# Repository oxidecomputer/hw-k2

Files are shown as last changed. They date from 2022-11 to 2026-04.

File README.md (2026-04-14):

# hw-k2



This design provides a PCIe extender that converts from
a U.2 PCIe device connector and provides a x4 PCIe CEM slot.

This is designed to work on *our* gimlet computer sled with a 
sharkfin PCIe riser.  Whether this can be generally used in
other applications is unknown.

This repository includes a 3d-printable encolosure design that
fits in our sled and provides brackets for both of the commonly
used NICs.

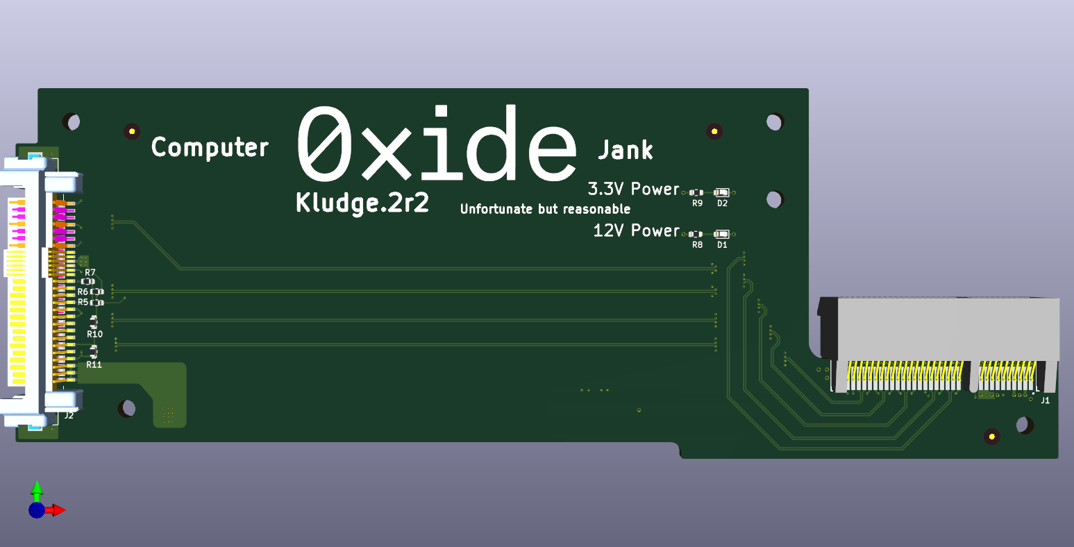
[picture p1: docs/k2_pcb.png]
PCB render


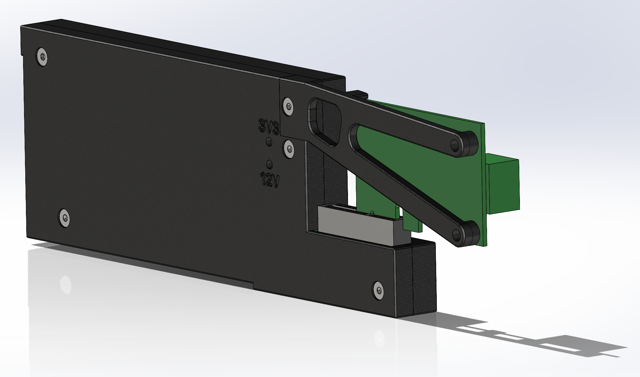
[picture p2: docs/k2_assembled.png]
exploded


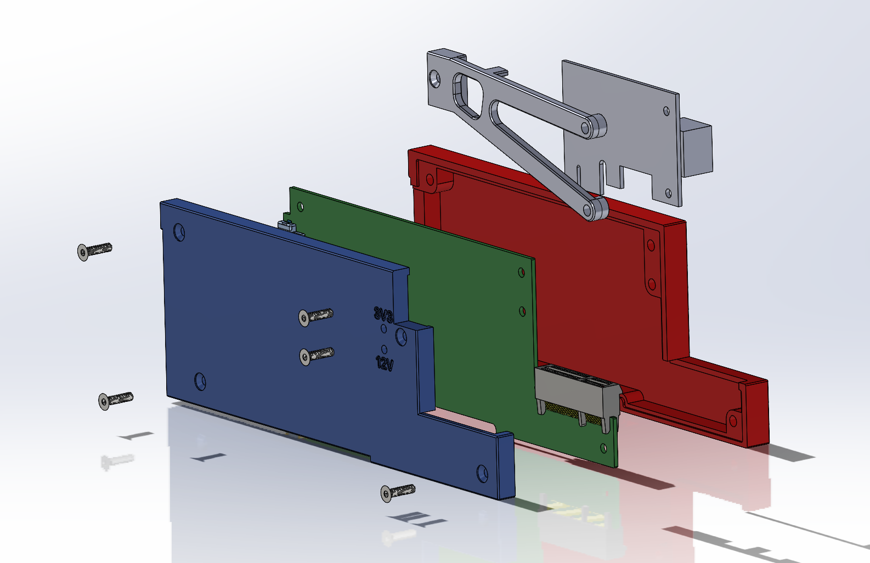
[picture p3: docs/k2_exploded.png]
assembled


[Mechanicals](mech_model)

# Status
The CAD represents a functional design.

# PLM

For the sake of clarity and consistency, the PLM-released files are renamed and
organized in the `plm` directory.

| PLM Name | Repo Name |
| --- | --- |
| 913-0000114_rev1_v1.d356 | gerbers/u2CEM.d356
| 913-0000114_rev1_v1_bom.xlsx | pulled out of the gerber zip
| 913-0000114_rev1_v1_gerbers.zip | gerbers/913-0000114_rev1.zip
| 913-0000114_rev1_v1_odb.zip | gerbers/u2CEM-odb.zip
| 913-0000114_rev1_v1_schematic.pdf | 913-0000114.pdf
| 913-0000114_rev1_v1_stackup.xlsx | stackup-K2-6lyr-FR408HR_rev4_26_MAR_2026.xlsx

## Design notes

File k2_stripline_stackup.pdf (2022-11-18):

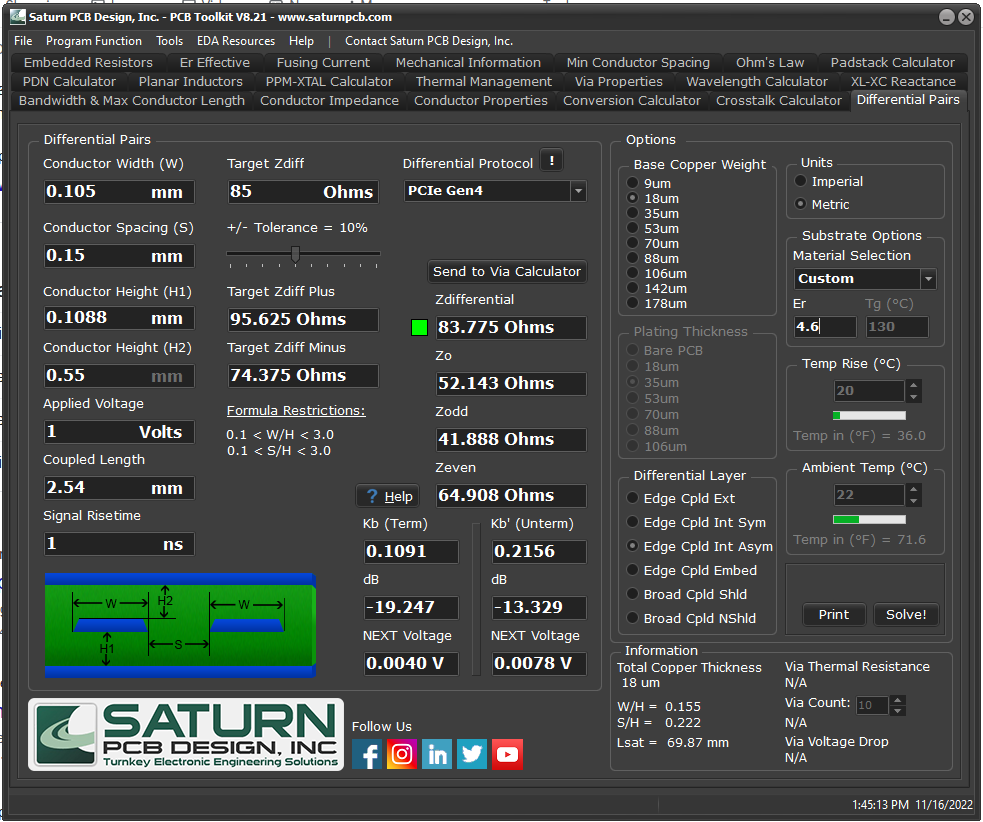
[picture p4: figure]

FR4 prepreg

Copper

FR4 prepreg

FR4 Core

Copper

IN2

IN3

IN4

FR4 Core
H = 0.55 mm
er = 4.6
tand = 0.02

FR4 Prepreg
H = 0.1088 mm
er = 4.25
tand = 0.02

Dielectric3

Dielectric4

Diagram is approximately to scale!
IN2, IN3, and IN4 copper thickness = 0.0152 mm (about 0.5 oz?)

Assume that the prepreg laminates itself in around the IN3 core traces

For 100 Ohm differential stripline: Trace width = 0.105 mm
Differential pair trace gap = 0.15 mm Zdiff (assume er=4.6) = 83.775 Ohms Zdiff (assume er = 4.25) = 87.157 Ohms

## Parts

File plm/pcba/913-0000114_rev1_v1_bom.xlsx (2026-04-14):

BOM: 913-0000103
Assembly Part Number/Revision: 913-0000103_rev1
Oxide Computer Company
Item # | Quantity per board | Manufacturer Part # | Do Not Install | Reference designators | Vendor (optional) | Vendor Part Number (optional) | Value (optional) | Size / Footprint (optional) | Part description/ specs (optional, but recommended) | Manfacturer (optional)
1 | 1 | GRM155R61E105KA12D |  | C1 | DigiKey | 490-10017-1-ND | 1uF |  | CAP CER 1UF 25V X5R 0402 | Murata Electronics
2 | 1 | RMCF0402FT10K0 | DNI | R1 | Digikey | RMCF0402FT10K0CT-ND | 10k |  | RES 10K OHM 1% 1/16W 0402 | Stackpole
3 | 4 | 5015 | DNI | TP1,TP2,TP3,TP4 | Digikey | 36-5015CT-ND |  |  | PC TEST POINT MINIATURE | Keystone
4 | 1 | SN74LVC1G07DBVR |  | U1 | Digikey | 296-8485-1-ND |  |  | IC BUFF NON-INVERT 5.5V SOT-23-5 | Texas Instruments
END OF BOM

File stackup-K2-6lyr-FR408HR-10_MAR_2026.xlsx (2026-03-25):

Design_Stackup
Customer |  | Oxide Computer Company
Board Title |  | K.2
Part Number |  | 913-0000114
Layer Count |  | 6L
Thickness (mils) |  | 62mil +/- 10%
Material |  | FR408HR
Copper Foil |  | Standard
Soldermask |  | Black
Other demands |  | N/A
Date |  | 2026-03-10
Revision |  | V01
Layer | Type | Material | Glass gabric (RC%) | Copper foil |  | Thickness |  | Dk @10GHz | Df @10GHz | Ref Plane | Differential ( trace / space )
 |  |  |  |  |  |  |  |  |  |  | 85 Ohm +/- 10%
 |  |  |  |  |  |  |  |  |  |  | Design LW | Actual LW
 |  |  |  | weight (oz) | type, Rz(um) | mils | Tolerance |  |  |  | mils | mils
 | SOLDERMASK | SOLDERMASK |  |  |  | 0.500 |  | 3.50 | 0.0190
L1 | CONDUCTOR |  |  | 1/4 OZ COPPER + PLATE |  | 1.450 |  |  |  | L2 | 5.5 / 11.5
 | Prepreg | FR408HR | 1086x1 RC65% |  |  | 2.996 |  | 3.26 | 0.0028
L2 | CONDUCTOR |  |  | 1 OZ COPPER |  | 1.400
 | Core | FR408HR | 2116x1 RC54% |  |  | 5.000 |  | 3.23 | 0.0042
L3 | CONDUCTOR |  |  | 1 OZ COPPER |  | 1.400 |  |  |  | L2 & L6 | 6.8 / 12.8
 | Prepreg | FR408HR | 106x1 RC75% 1080x1 RC71% 106x1 RC75% |  |  | 7.536
 | Core | FR408HR | 50% |  |  | 21.000 |  | 3.53 | 0.0098
 | Prepreg | FR408HR | 106x1 RC75% 1080x1 RC71% 106x1 RC75% |  |  | 7.536
L4 | CONDUCTOR |  |  | 1 OZ COPPER |  | 1.400
 | Core | FR408HR | 1078x1 RC68% |  |  | 5.000 |  | 3.23 | 0.0042
L5 | CONDUCTOR |  |  | 1 OZ COPPER |  | 1.400
 | Prepreg | FR408HR | 1078x2 RC73% |  |  | 2.996 |  | 3.17 | 0.0042
L6 | CONDUCTOR |  |  | 1/4 OZ COPPER + PLATE |  | 1.450 |  |  |  | L5 | 5.5 / 11.5
 | SOLDERMASK | SOLDERMASK |  |  |  | 0.500 |  | 3.50 | 0.0190
thickness (conductor+plate) |  |  |  |  |  | 60.5640
thicknes + soldermask |  |  |  |  |  | 61.5640

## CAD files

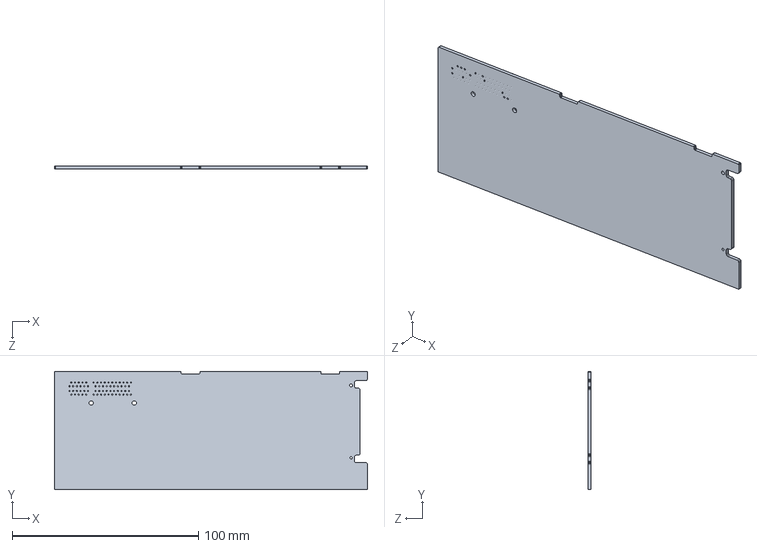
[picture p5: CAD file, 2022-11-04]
mech_model/u2CEM_v3.SLDASM
168.0 x 63.5 x 1.60 mm

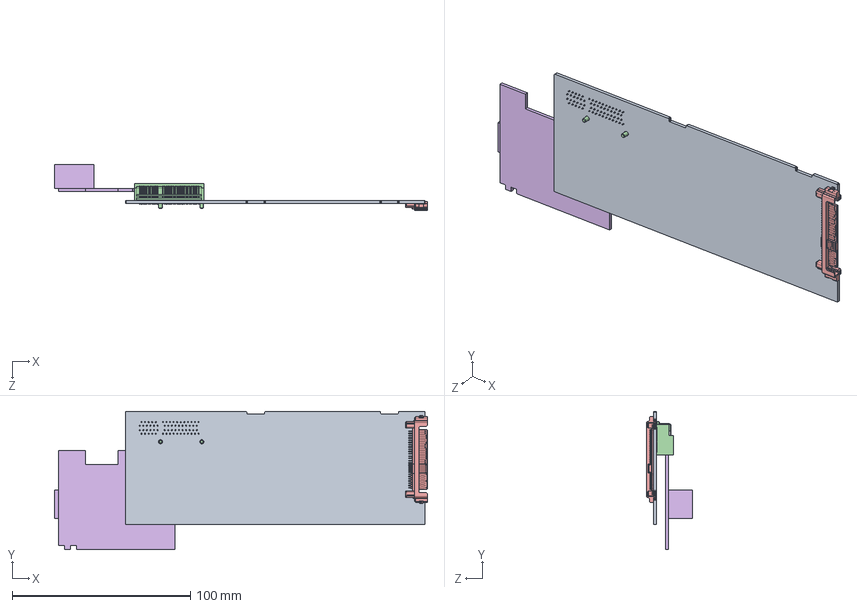
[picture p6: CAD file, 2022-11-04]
mech_model/K2v2.SLDASM
209.1 x 77.4 x 25.7 mm
u2CEM PCB.step
PCIE-064-02-F-D-RA_pins2.step
PCIE-064-02-F-D-RA_pins1.step
PCIE-064-02-F-D-RA_body.step
3d_model_psas4m213002xxx
CEM_NIC

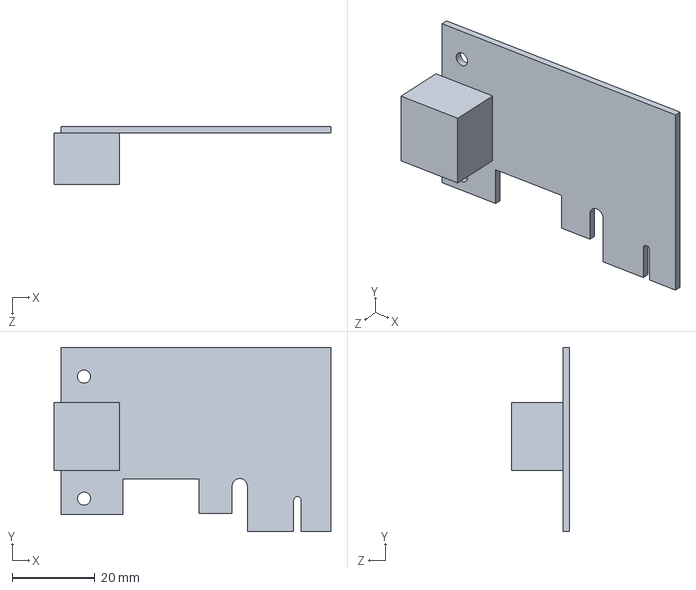
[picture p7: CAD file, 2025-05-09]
mech_model/StarTech_intel_nic.SLDPRT
67.0 x 44.6 x 14.1 mm

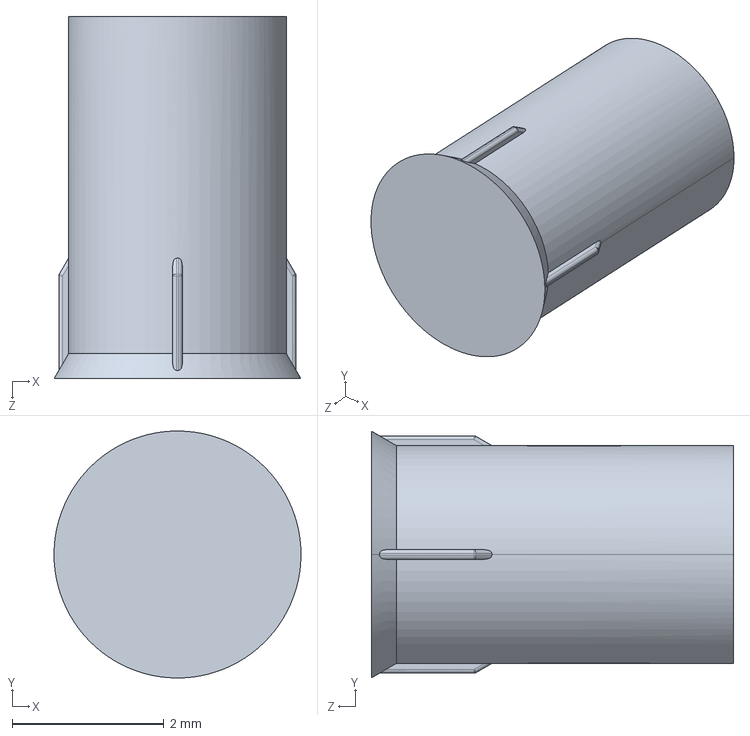
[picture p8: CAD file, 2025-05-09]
mech_model/PLPC3-188.SLDPRT
3.25 x 3.25 x 4.78 mm

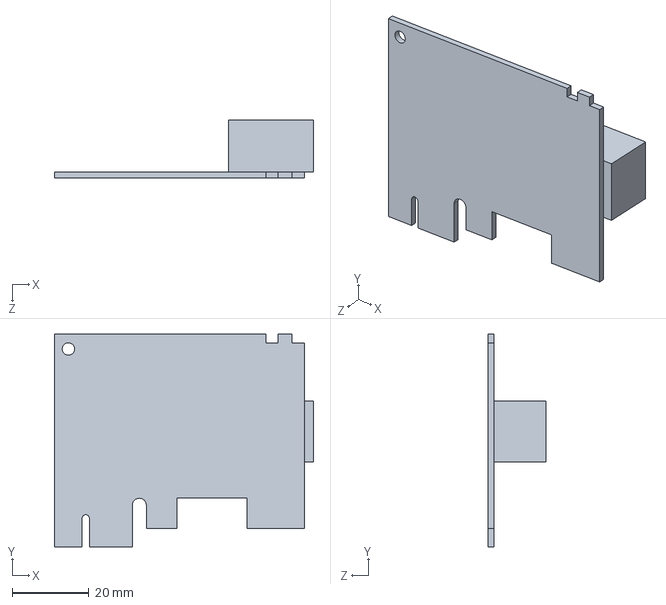
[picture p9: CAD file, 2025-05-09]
mech_model/CEM_NIC.SLDPRT
67.6 x 55.5 x 15.1 mm

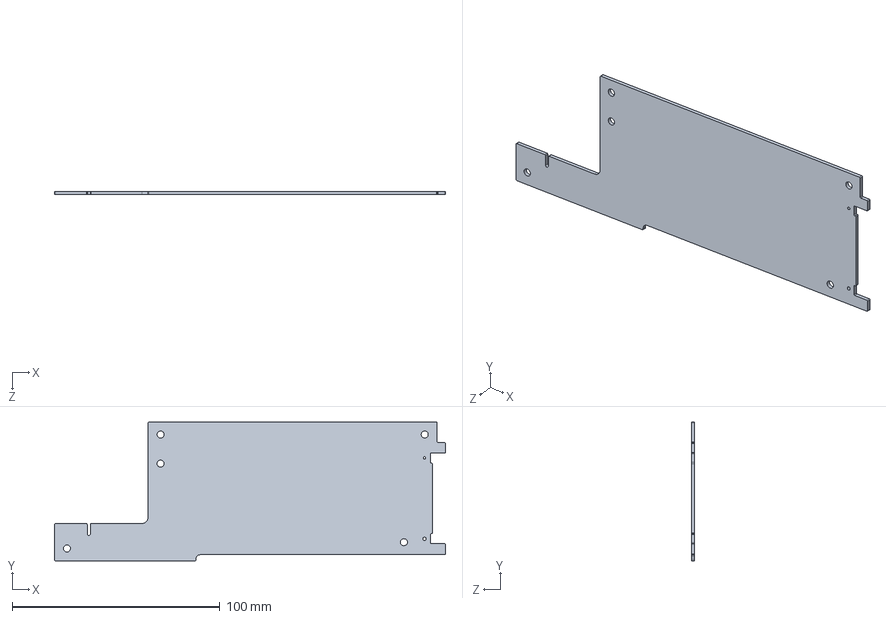
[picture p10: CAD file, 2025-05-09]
mech_model/U2_CEM_EM.SLDPRT
188.0 x 66.8 x 1.60 mm

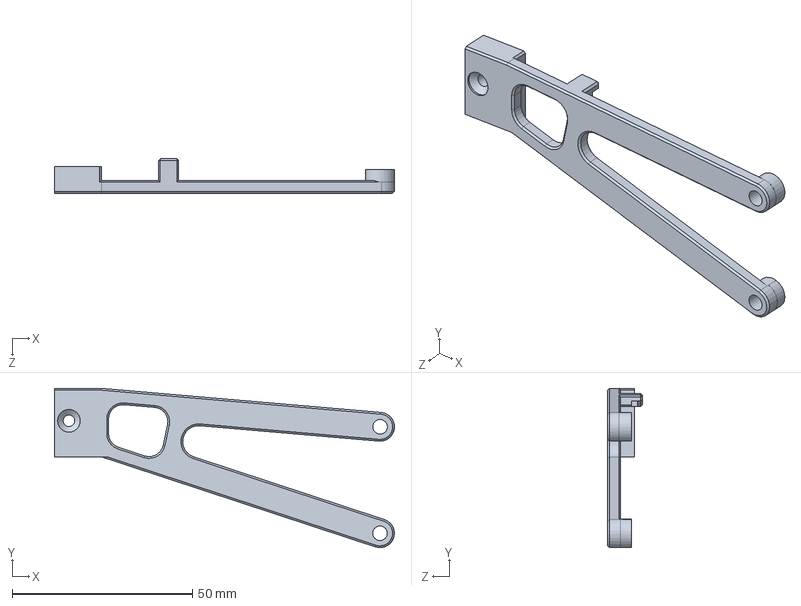
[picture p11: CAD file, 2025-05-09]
mech_model/StarTech_intel_nic_support.SLDPRT
94.3 x 44.2 x 9.57 mm

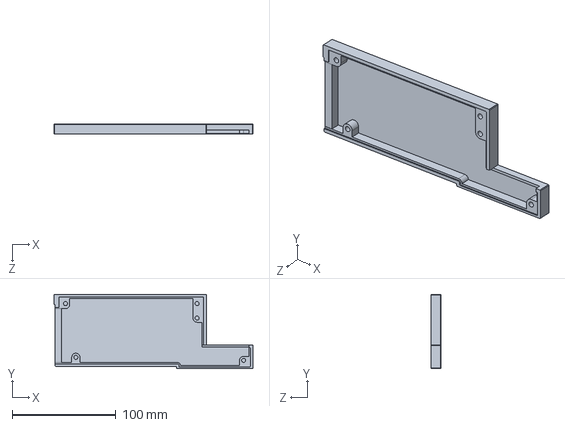
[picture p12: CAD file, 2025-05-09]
mech_model/CEM_EM_RIGHT_COVER_MIRROR.SLDPRT
192.1 x 71.8 x 10.1 mm

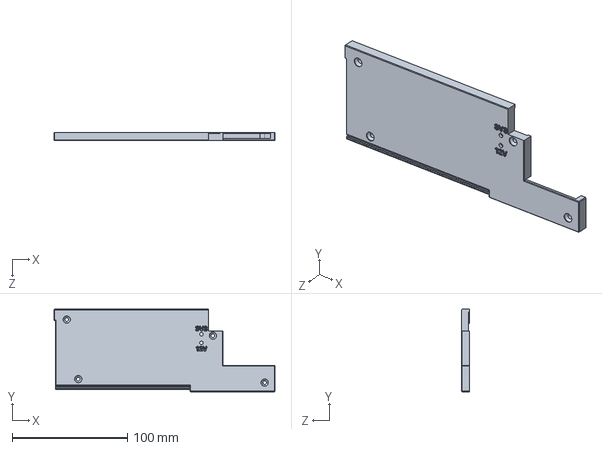
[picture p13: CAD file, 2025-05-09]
mech_model/CEM_EM_LEFT_COVER.SLDPRT
192.1 x 71.8 x 7.38 mm

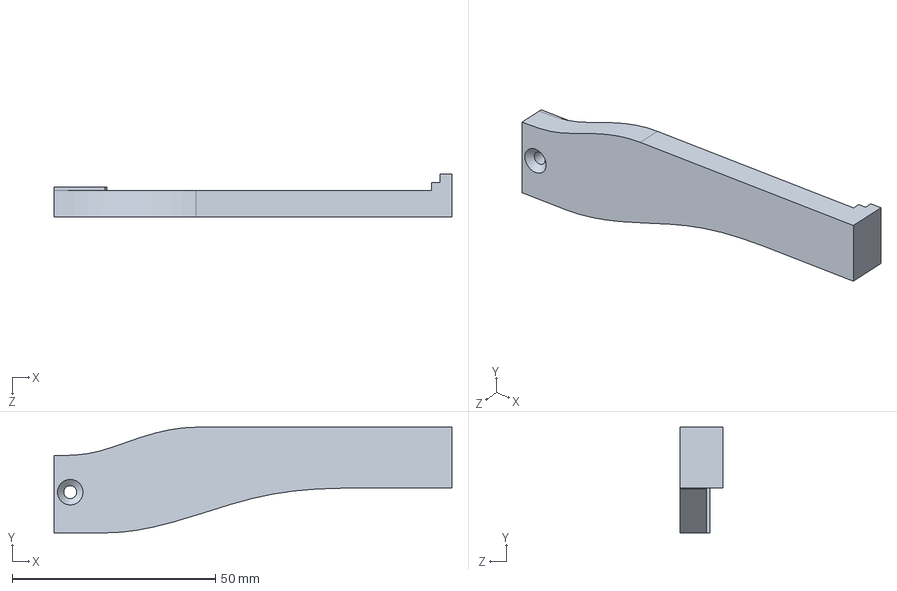
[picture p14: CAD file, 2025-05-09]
mech_model/CEM_NIC_SUPPORT.SLDPRT
98.0 x 26.0 x 10.5 mm

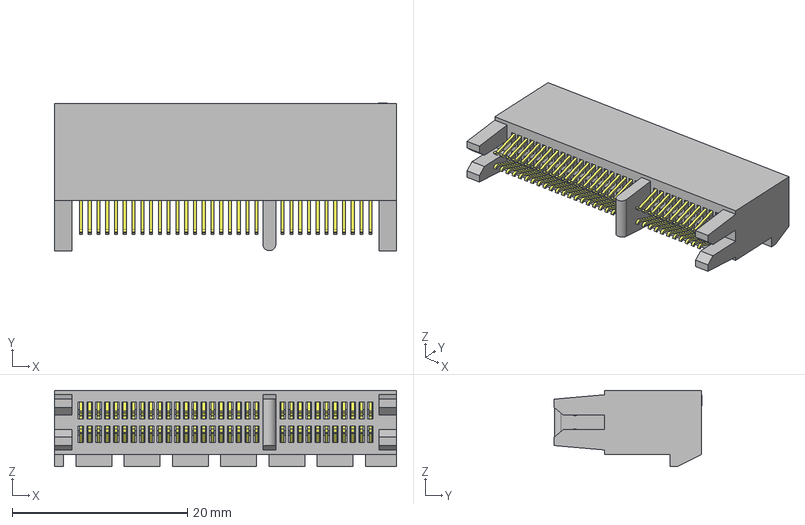
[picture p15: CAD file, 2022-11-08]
mech_model/PCIE-064-02-S-D-EMS2-BG.stp
39.0 x 16.8 x 8.70 mm
PCIE-064-02-S-D-EMS2-BG_pins1
PCIE-064-02-S-D-EMS2-BG_body

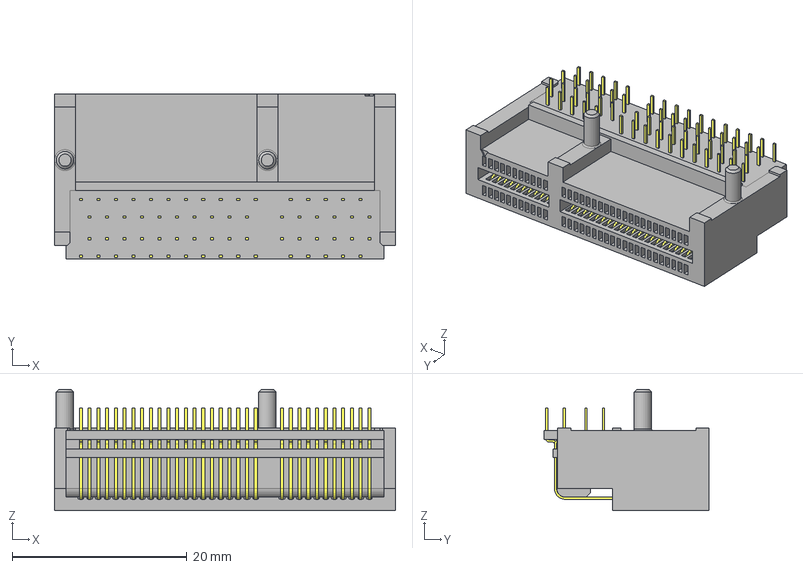
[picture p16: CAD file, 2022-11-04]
mech_model/PCIE-064-02-X-D-RA.step
39.0 x 18.9 x 13.9 mm
PCIE-064-02-F-D-RA_pins2
PCIE-064-02-F-D-RA_pins1
PCIE-064-02-F-D-RA_body

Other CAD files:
mech_model/K2v3.SLDASM
mech_model/PCIE_064_02_F_D_RA.sldasm
mech_model/PCIE_064_02_S_D_EMS2_BG_3.sldprt
mech_model/CEM_EM_LEFT_COVER_COSMO.STL
mech_model/PCIE_064_02_S_D_EMS2_BG_5.sldprt
mech_model/CEM_EM_LEFT_COVER_MIRROR.SLDPRT
mech_model/10018783-x0xxx_64c.stp
mech_model/92125A132_18-8 Stainless Steel Hex Drive Flat Head Screw.SLDPRT
mech_model/94459A130_Heat-Set Inserts for Plastic.SLDPRT
mech_model/94500A221_316 Stainless Steel Button Head Hex Drive Screws.SLDPRT
mech_model/95893A175_Flat Head Thread-Forming Screws for Plastic(1).SLDPRT
mech_model/99397A077_Torx Plus Rounded Head Thread-Forming Screws.SLDPRT
mech_model/CEM_EM_LEFT_COVER.STL
mech_model/CEM_EM_RIGHT_COVER.SLDPRT
mech_model/CEM_EM_RIGHT_COVER_MIRROR.STL
mech_model/CEM_NIC_SUPPORT.STL
mech_model/MirrorCEM_EM_LEFT_COVER.SLDPRT
mech_model/PCIE-064-02-X-D-RA.SLDASM
mech_model/PCIE_064_02_F_D_RA_3.sldprt
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

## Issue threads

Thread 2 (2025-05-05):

K.2 chassis needs a diet to be Cosmo ready

Aaron-Hartwig, 2025-05-05:
Check out @ericaasen's comment [in chat](https://matrix.to/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), but I'll hit the relevant bits here.

The K.2 is just a little too thick to fit in the Cosmo drive bay and is binding on the hemostats:

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

>eric: Looks like the K.2 is about 17.29mm thick
>eric: Which is 0.29mm over tolerance since the 2.5” drive spec calls out the thickness as 17mm +0/-0.5mm
...
>doug: That is intentional on the Cosmo design- the thickest part of the U.2 drive-in-tray rides under this guide.

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

We would want the new K.2 to be differentiable from the original K.2 as clearly as possible. This may be less obvious as we'd like since the ESD material is all black<sup>citation needed</sup>.

Aaron-Hartwig, 2025-05-14:
I believe @ericaasen accomplished this in https://github.com/oxidecomputer/hw-k2/commit/a43d913b8c510b053cf099e3ce276ad57e1525b2

Closed 2025-05-14.

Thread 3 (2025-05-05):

Need to order many new K.2 enclosures

Aaron-Hartwig, 2025-05-05:
Once we close #2, we need to replace all existing K.2s. We have several of these in the manufacturing, another several in home labs, and then I'd assume a few dozen at the office. We anticipate needing to order something like 50-60 of these. We should get printing these quoted out.

ericaasen, 2025-05-14:
These were ordered from Xometry.  There are 50 replacement covers to allow for existing K.2 upgrades and 50 sets for new K.2s

Order Details
Quote ID: Q44-4284-2418
Order Number: 10A336-15000

Part Id: 084FB42
Filename: CEM_EM_LEFT_COVER_COSMO.STL
Process: 3D Printing
Technology: Fused Deposition Modeling (FDM)
Material: ABS-ESD7, Color: Black, Infill: Solid
Finish: Standard
Threads and Tapped Holes: None
Inserts: None
Inspection: Standard Inspection
x 100 	$24.27
 	$2,427.00

Part Id: 084FB2A
Filename: CEM_EM_RIGHT_COVER_MIRROR.STL
Process: 3D Printing
Technology: Fused Deposition Modeling (FDM)
Material: ABS-ESD7, Color: Black, Infill: Solid
Finish: Standard
Threads and Tapped Holes: None
Inserts: None
Inspection: Standard Inspection
x 50 	$24.59
 	$1,229.50

Part Id: 084FC11
Filename: StarTech_intel_nic_support.STL
Process: 3D Printing
Technology: Fused Deposition Modeling (FDM)
Material: ABS-ESD7, Color: Black, Infill: Solid
Finish: Standard
Threads and Tapped Holes: None
Inserts: None
Inspection: Standard Inspection
x 50 	$7.55
 	$377.50
Subtotal	$4,034.00
Shipping	Free Shipping for small parcels
Free shipping is applicable for small parcel orders. Freight shipments will be subject to shipping charges.
Tax 	$201.71
Total 	$4,235.71

ericaasen, 2025-05-14:
Estimated ship date is May 14 and they are shipping via 2-day air, so they should arrive at my house Friday or Saturday.  As soon as I get them, I'll send a pile of updated covers to EMY.  If you know how many you want, I can make sure to send that many, but I don't want to send more than needed since we also have a bunch of these spread around and if they're all in EMY, someone there has to deal with shipping them out.

Aaron-Hartwig, 2025-06-10:
30 of the slimmer enclosure halves have made it to the office (swapping progress tracked by https://github.com/oxidecomputer/meta/issues/667). Eric received the brand new K.2 enclosures and will work with Nathanael to build them up into complete units.

Closed 2025-06-10.

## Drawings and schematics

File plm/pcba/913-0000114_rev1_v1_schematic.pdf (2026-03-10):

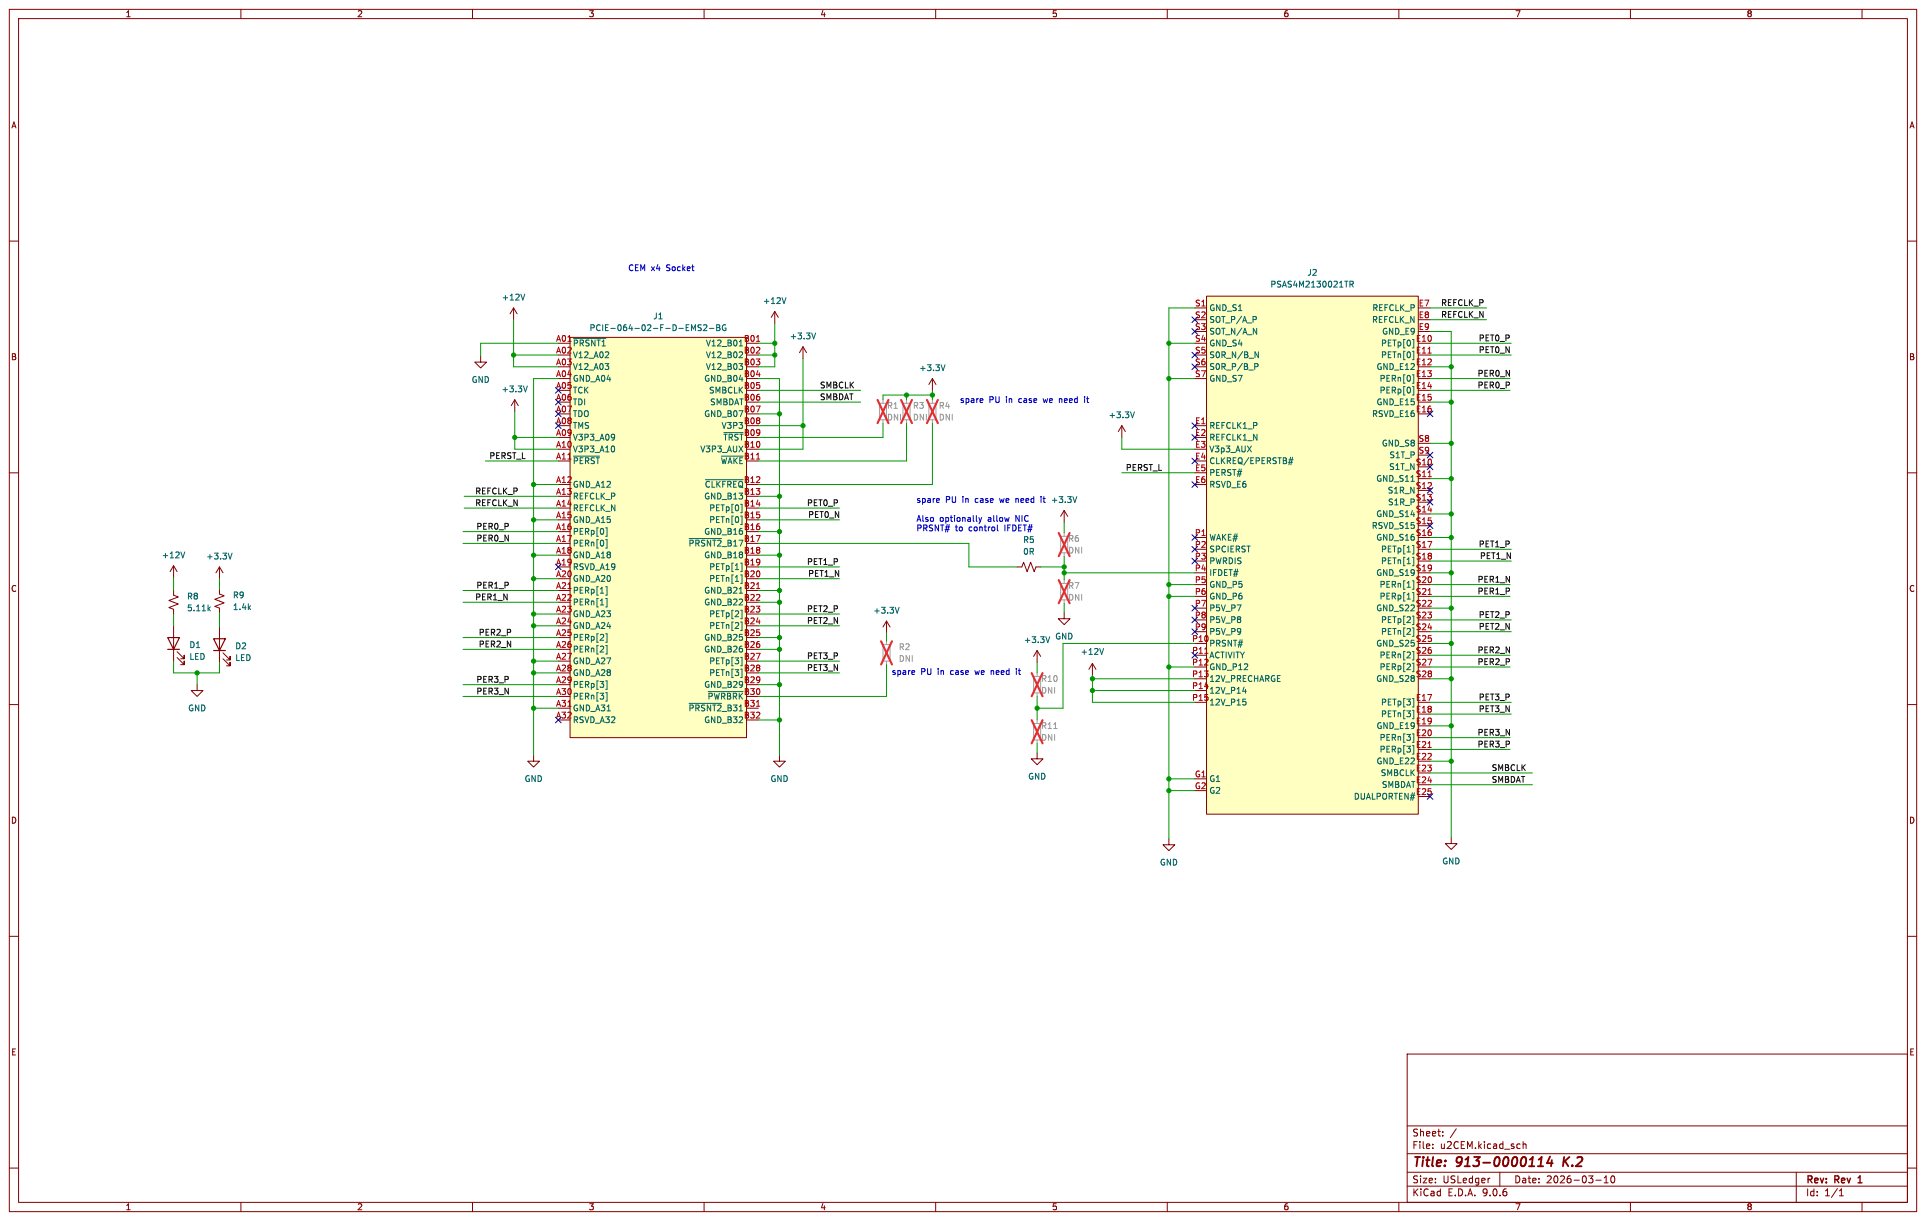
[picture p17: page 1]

J2 PSAS4M2130021TR
GND_S1 S1 SOT_P/A_P S2 SOT_N/A_N S3 GND_S4 S4 S0R_N/B_N S5 S0R_P/B_P S6 GND_S7 S7 REFCLK1_P E1 REFCLK1_N E2 V3p3_AUX E3 CLKREQ/EPERSTB# E4 PERST# E5 RSVD_E6 E6 WAKE# P1 SPCIERST P2 PWRDIS P3

REFCLK_P REFCLK_N
REFCLK_P E7 REFCLK_N E8 GND_E9 E9 PETp[0] E10 PETn[0] E11 GND_E12 E12 PERn[0] E13 PERp[0] E14 GND_E15 E15 RSVD_E16 E16 GND_S8 S8 S1T_P S9 S1T_NS10 GND_S11 S11 S1R_N S12 S1R_P S13 GND_S14 S14 RSVD_S15 S15 GND_S16 S16 PETp[1] S17 PETn[1] S18 GND_S19 S19 PERn[1] S20 PERp[1] S21 GND_S22 S22 PETp[2] S23 PETn[2] S24 GND_S25 S25 PERn[2] S26 PERp[2] S27 GND_S28 S28 PETp[3] E17 PETn[3] E18 GND_E19 E19 PERn[3] E20 PERp[3] E21 GND_E22 E22 SMBCLK E23 SMBDATE24 DUALPORTEN# E25

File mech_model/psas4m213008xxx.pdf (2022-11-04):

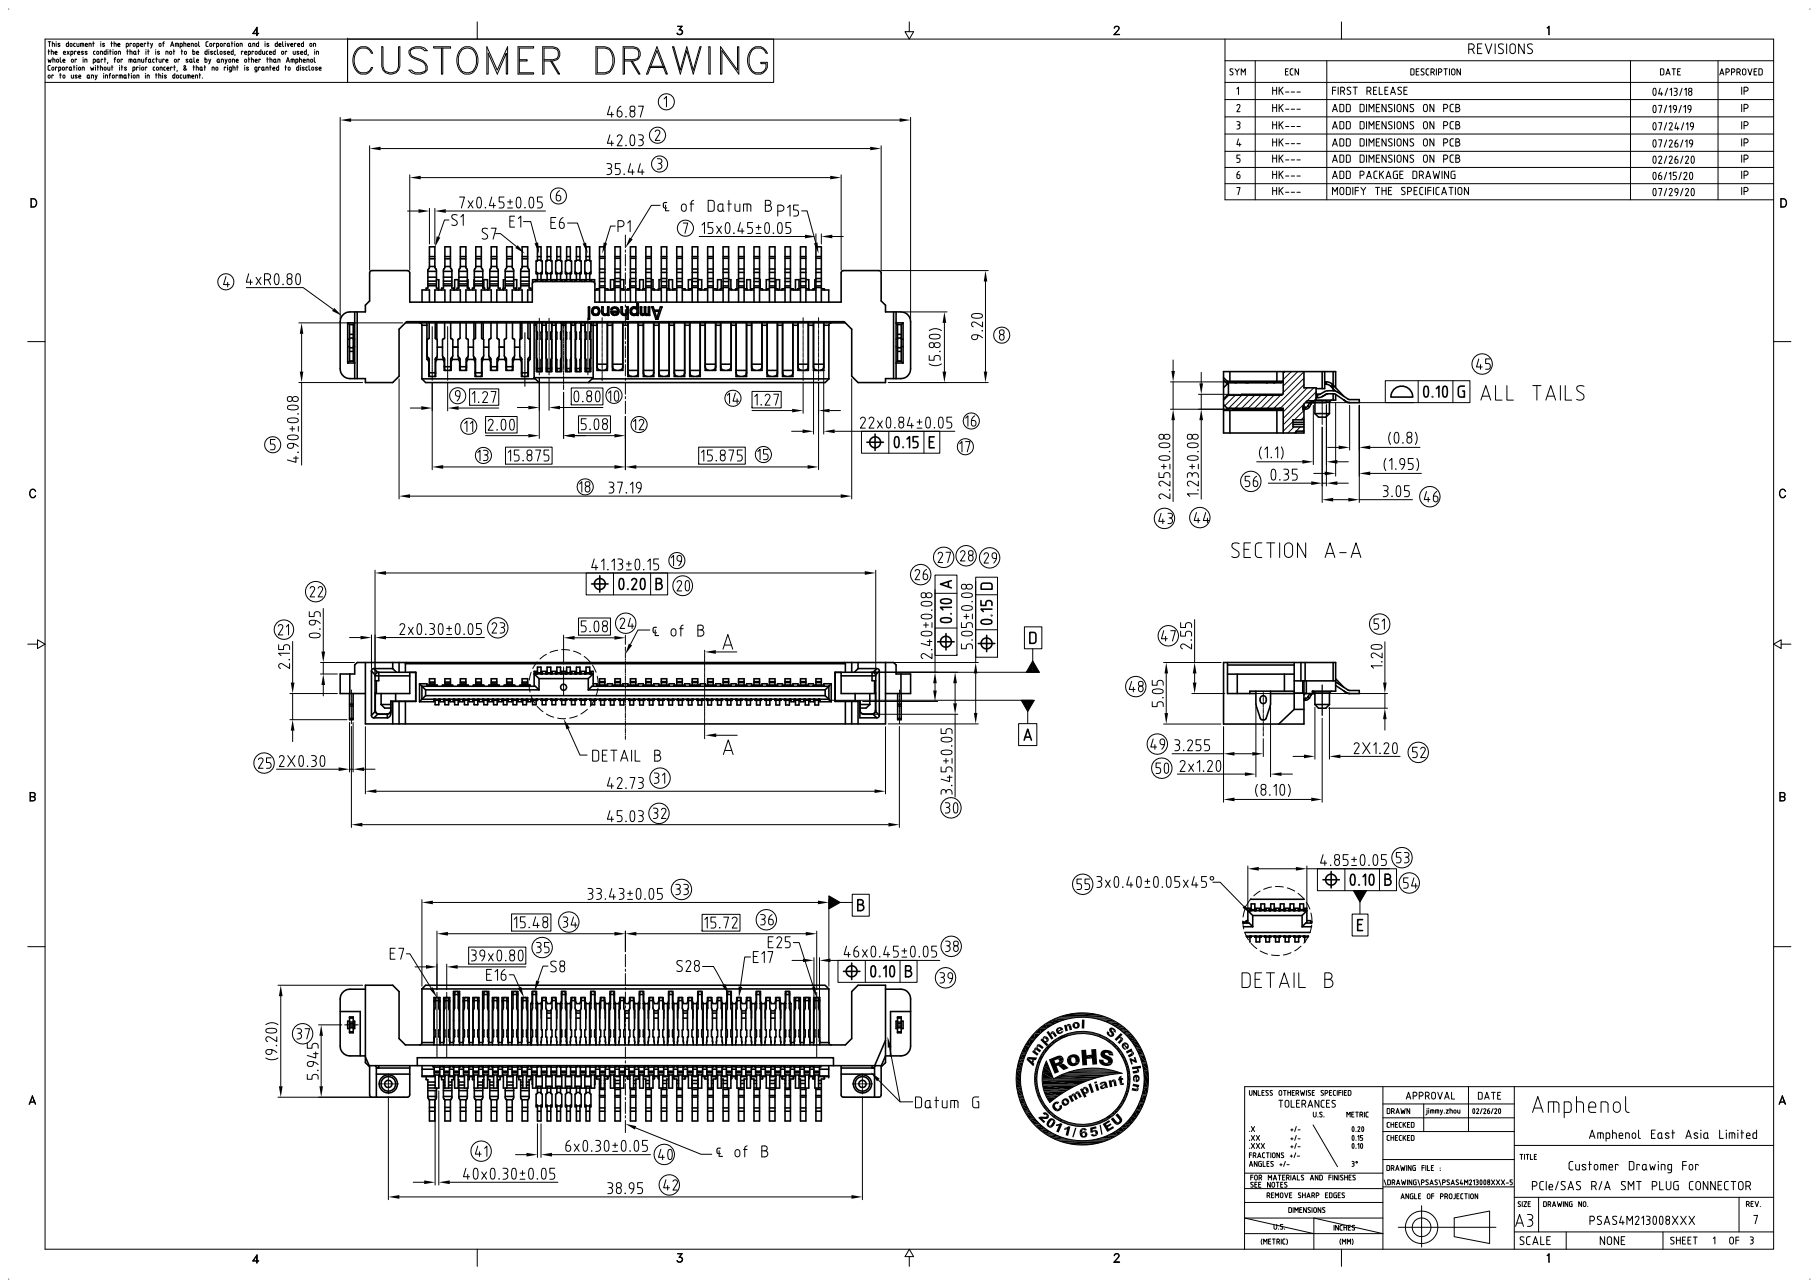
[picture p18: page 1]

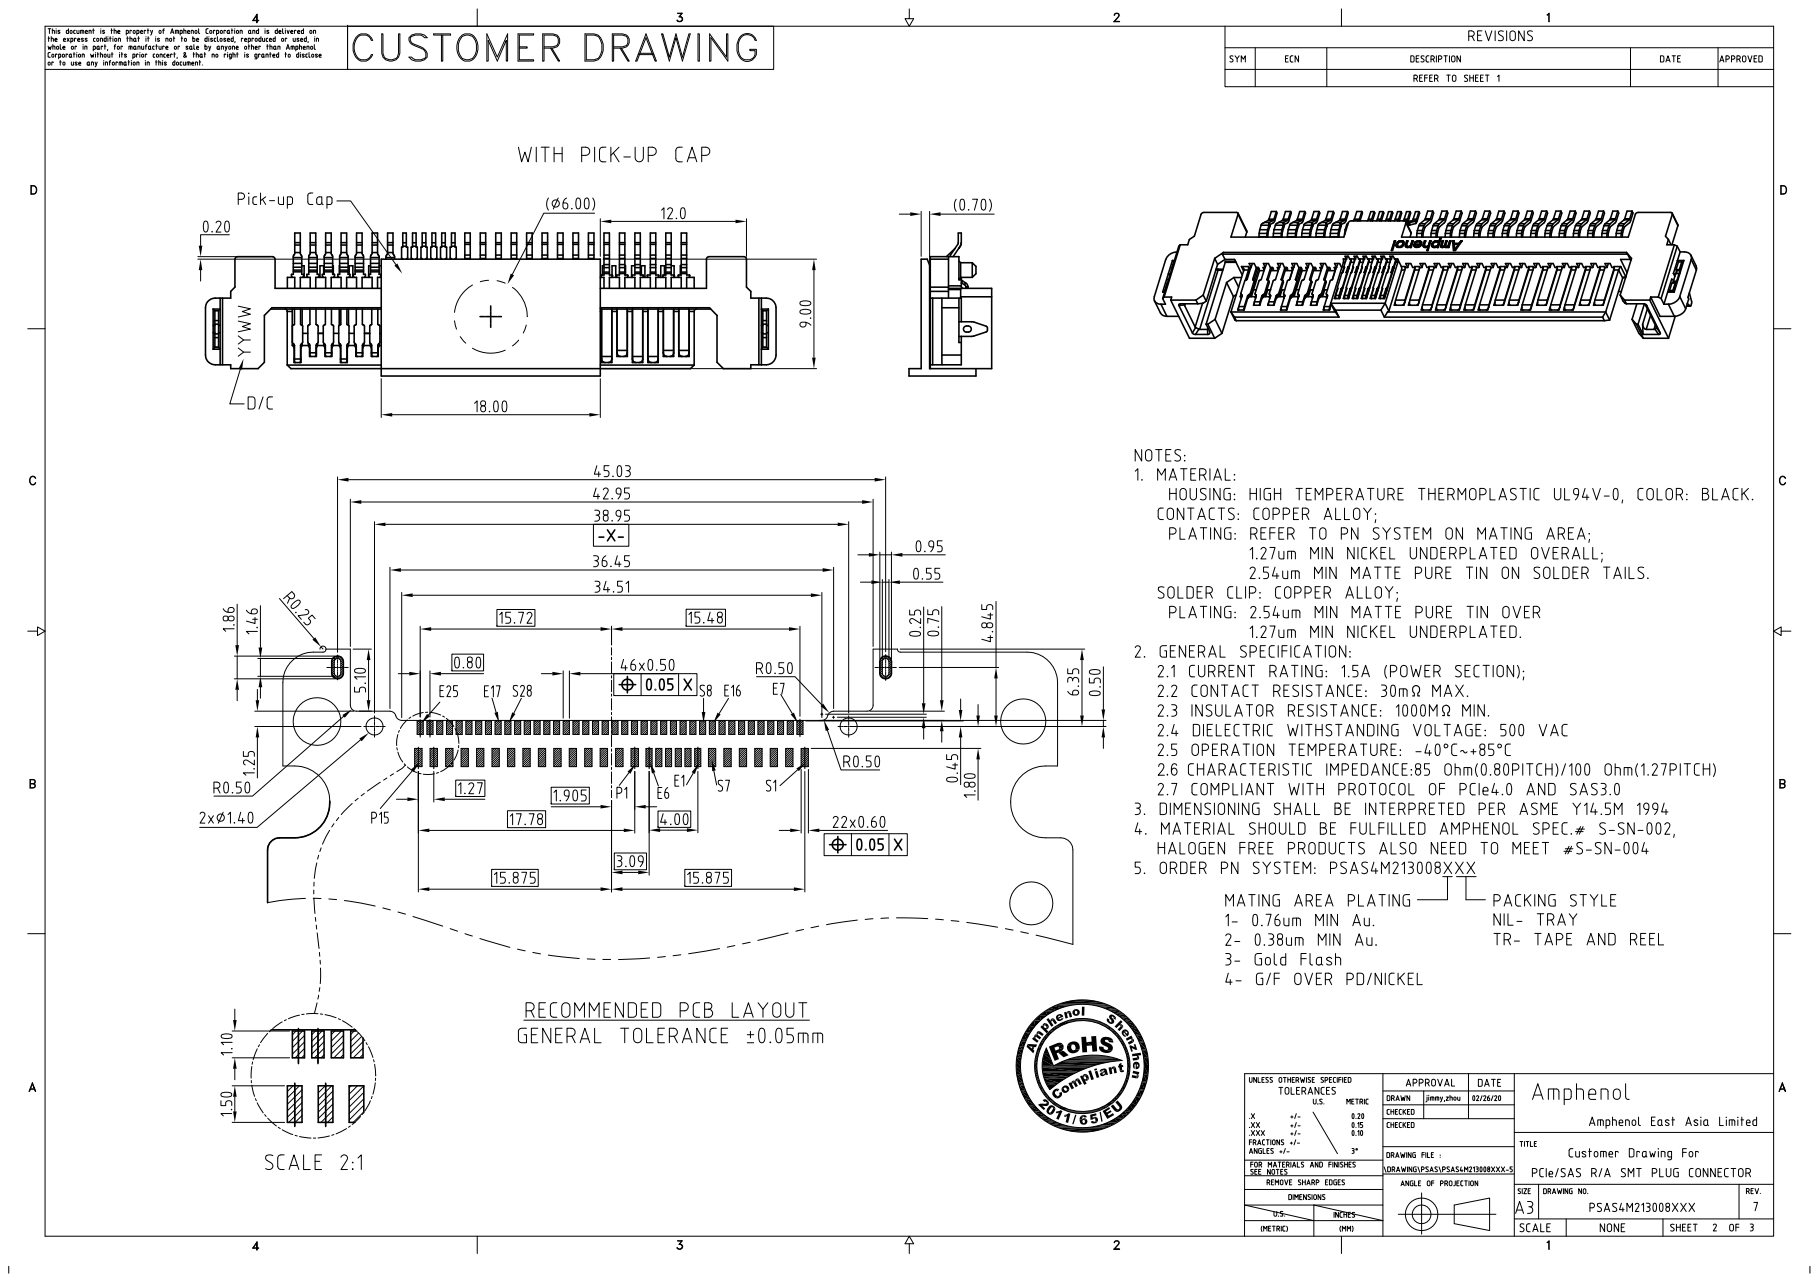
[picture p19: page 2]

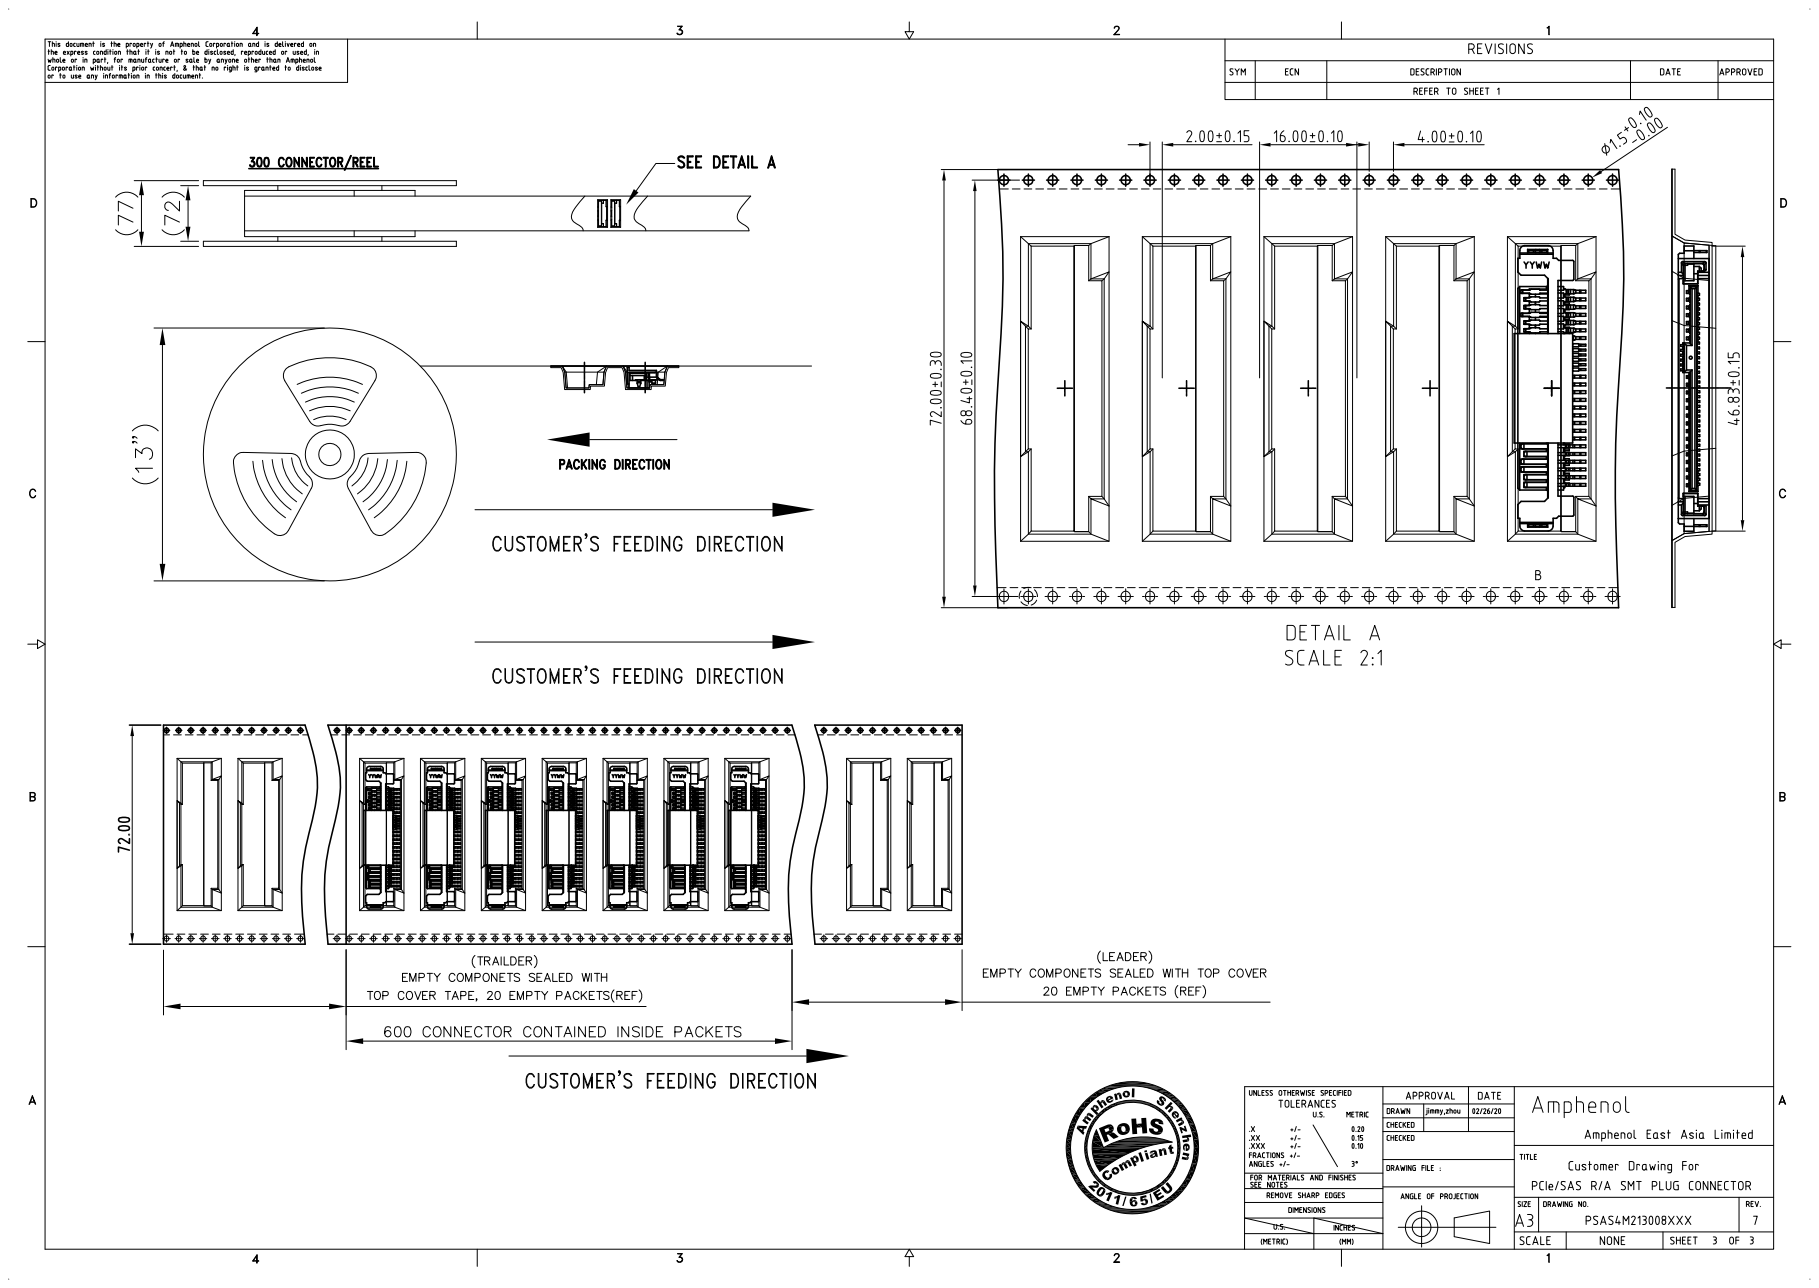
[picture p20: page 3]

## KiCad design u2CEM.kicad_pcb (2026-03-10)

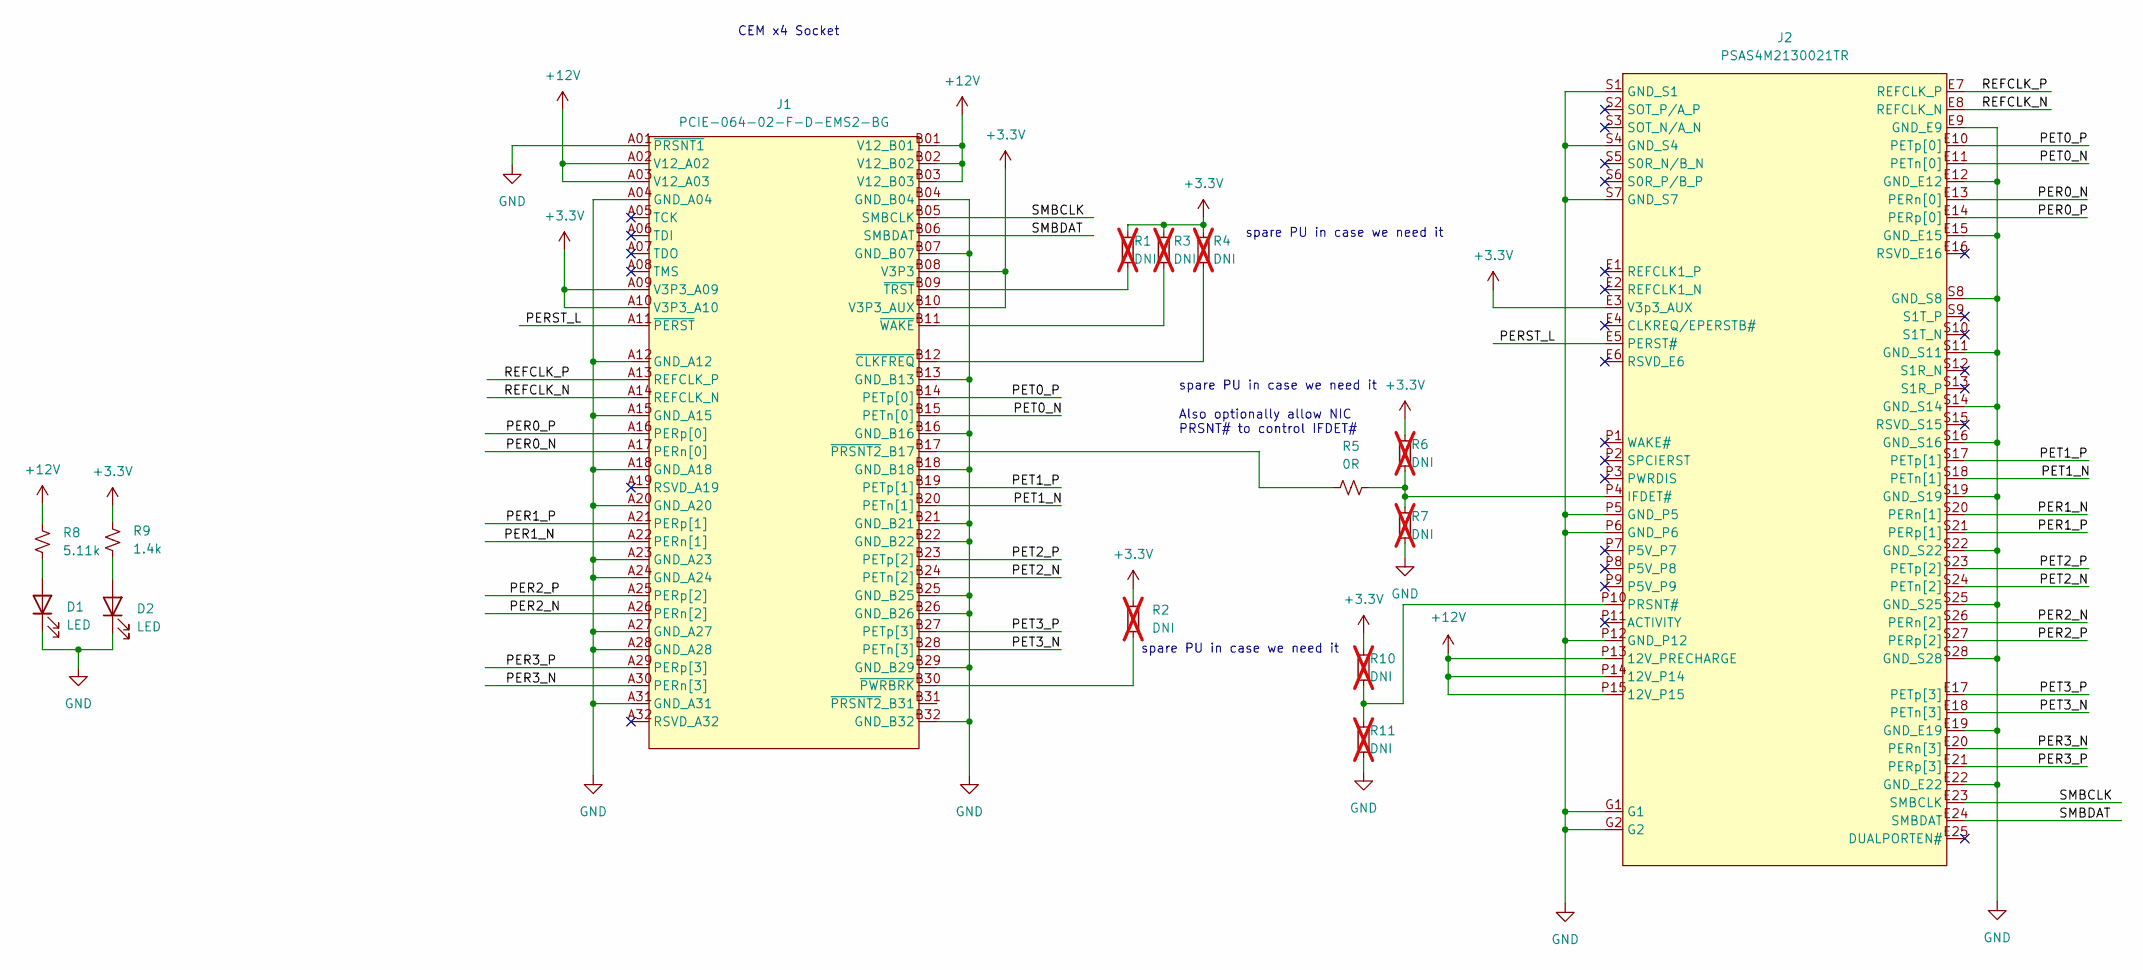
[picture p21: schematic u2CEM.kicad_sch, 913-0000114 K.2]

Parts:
D1, D2: LED; LED_0603_1608Metric; MPN LTST-C193KSKT-5A
J1: PCIE-064-02-F-D-EMS2-BG; SAMTEC_PCIE-064-02-X-D-EMS2-BG; MPN PCIE-064-02-F-D-EMS2-BG
J2: PSAS4M2130021TR; MPN PSAS4M2130021TR
R1, R2, R3, R4, R6, R7, R10, R11: DNI; R_0603_1608Metric; not fitted
R5: 0R; R_0603_1608Metric; MPN RC0603JR-070RL
R8: 5.11k; R_0603_1608Metric; MPN RC0603FR-075K11L
R9: 1.4k; R_0603_1608Metric; MPN RC0603FR-071K4L

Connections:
+3.3V: J1.A09 (V3P3_A09), J1.A10 (V3P3_A10), J1.B08 (V3P3), J1.B10 (V3P3_AUX), J2.E3 (V3p3_AUX), R1.1, R2.1, R3.1, R4.1, R6.1, R9.1, R10.1
+12V: J1.A02 (V12_A02), J1.A03 (V12_A03), J1.B01 (V12_B01), J1.B02 (V12_B02), J1.B03 (V12_B03), J2.P13 (12V_PRECHARGE), J2.P14 (12V_P14), J2.P15 (12V_P15), R8.1
/PER0_N: J1.A17 (PERn[0]), J2.E13 (PERn[0])
/PER0_P: J1.A16 (PERp[0]), J2.E14 (PERp[0])
/PER1_N: J1.A22 (PERn[1]), J2.S20 (PERn[1])
/PER1_P: J1.A21 (PERp[1]), J2.S21 (PERp[1])
/PER2_N: J1.A26 (PERn[2]), J2.S26 (PERn[2])
/PER2_P: J1.A25 (PERp[2]), J2.S27 (PERp[2])
/PER3_N: J1.A30 (PERn[3]), J2.E20 (PERn[3])
/PER3_P: J1.A29 (PERp[3]), J2.E21 (PERp[3])
/PERST_L: J1.A11 (~PERST), J2.E5 (PERST#)
/PET0_N: J1.B15 (PETn[0]), J2.E11 (PETn[0])
/PET0_P: J1.B14 (PETp[0]), J2.E10 (PETp[0])
/PET1_N: J1.B20 (PETn[1]), J2.S18 (PETn[1])
/PET1_P: J1.B19 (PETp[1]), J2.S17 (PETp[1])
/PET2_N: J1.B24 (PETn[2]), J2.S24 (PETn[2])
/PET2_P: J1.B23 (PETp[2]), J2.S23 (PETp[2])
/PET3_N: J1.B28 (PETn[3]), J2.E18 (PETn[3])
/PET3_P: J1.B27 (PETp[3]), J2.E17 (PETp[3])
/REFCLK_N: J1.A14 (REFCLK_N), J2.E8 (REFCLK_N)
/REFCLK_P: J1.A13 (REFCLK_P), J2.E7 (REFCLK_P)
/SMBCLK: J1.B05 (SMBCLK), J2.E23 (SMBCLK)
/SMBDAT: J1.B06 (SMBDAT), J2.E24 (SMBDAT)
GND: D1.1 (K), D2.1 (K), J1.A01 (~PRSNT1), J1.A04 (GND_A04), J1.A12 (GND_A12), J1.A15 (GND_A15), J1.A18 (GND_A18), J1.A20 (GND_A20), J1.A23 (GND_A23), J1.A24 (GND_A24), J1.A27 (GND_A27), J1.A28 (GND_A28), J1.A31 (GND_A31), J1.B04 (GND_B04), J1.B07 (GND_B07), J1.B13 (GND_B13), J1.B16 (GND_B16), J1.B18 (GND_B18), J1.B21 (GND_B21), J1.B22 (GND_B22), J1.B25 (GND_B25), J1.B26 (GND_B26), J1.B29 (GND_B29), J1.B32 (GND_B32), J2.E9 (GND_E9), J2.E12 (GND_E12), J2.E15 (GND_E15), J2.E19 (GND_E19), J2.E22 (GND_E22), J2.G1, J2.G2, J2.P5 (GND_P5), J2.P6 (GND_P6), J2.P12 (GND_P12), J2.S1 (GND_S1), J2.S4 (GND_S4), J2.S7 (GND_S7), J2.S8 (GND_S8), J2.S11 (GND_S11), J2.S14 (GND_S14), J2.S16 (GND_S16), J2.S19 (GND_S19), J2.S22 (GND_S22), J2.S25 (GND_S25), J2.S28 (GND_S28), R7.2, R11.2
unnamed: D1.2 (A), R8.2
unnamed: D2.2 (A), R9.2
unnamed: J1.B12 (~CLKFREQ), R4.2
unnamed: J1.B17 (~PRSNT2_B17), R5.1
unnamed: J1.B30 (~PWRBRK), R2.2
unnamed: J1.B09 (~TRST), R1.2
unnamed: J1.B11 (~WAKE), R3.2
unnamed: J2.P4 (IFDET#), R5.2, R6.2, R7.1
unnamed: J2.P10 (PRSNT#), R10.2, R11.1

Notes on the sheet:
CEM x4 Socket
spare PU in case we need it Also optionally allow NIC PRSNT# to control IFDET#
spare PU in case we need it

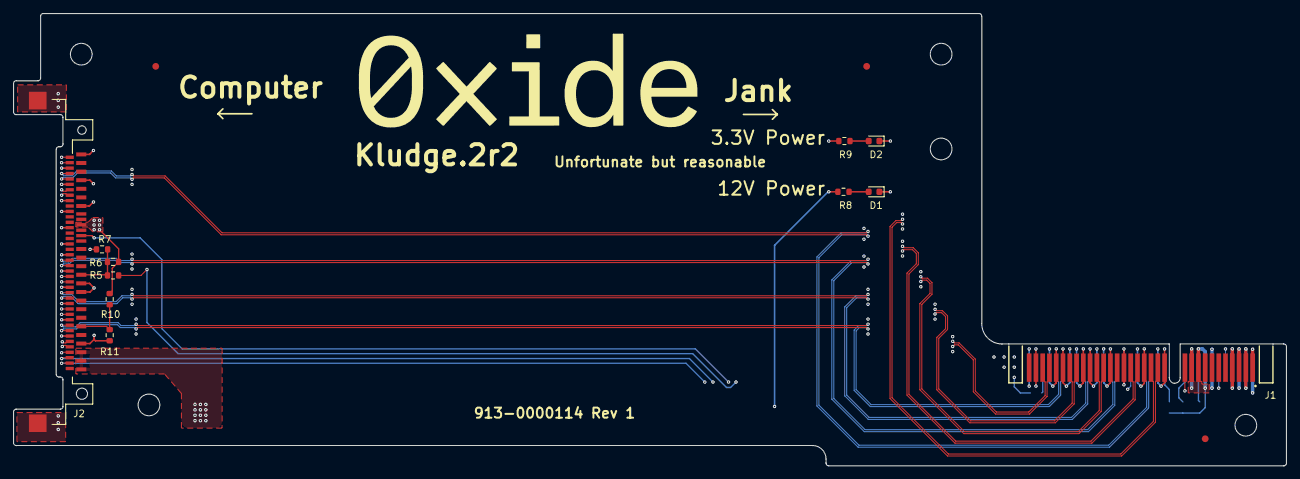
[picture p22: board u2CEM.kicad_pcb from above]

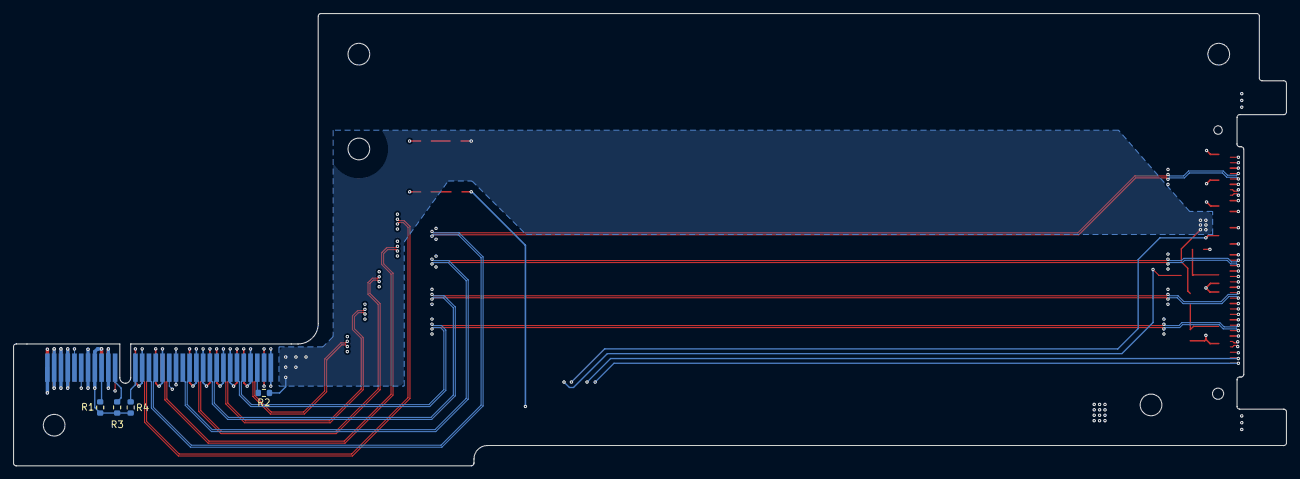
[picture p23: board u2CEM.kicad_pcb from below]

Board: 6 copper layers, 188.0 x 66.8 mm, 15 parts (4 on the bottom side), 33 nets.

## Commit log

2022-11-04 new version
    [10018783-x0xxx_64c.stp, 92125A132_18-8 Stainless Steel Hex Drive Flat Head Screw.SLDPRT, 94459A130_Heat-Set Inserts for Plastic.SLDPRT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]
2022-11-08 fixed outline and DRCs
    [95893A175_Flat Head Thread-Forming Screws for Plastic(1).SLDPRT, PCIE-064-02-S-D-EMS2-BG.stp, u2CEM.kicad_pcb]
2022-11-16 deleting old gerbers
2022-11-18 Package sent to tapeout
    final PCB package with updated trace width/spacing based on Ian calculating the required dimensions correctly instead of doing it wrong like I did.
    MCAD design still in flux
    [u2CEM.kicad_pcb]
2023-02-24 Finalized mech model with all hardware
    [92125A132_18-8 Stainless Steel Hex Drive Flat Head Screw.SLDPRT, 94459A130_Heat-Set Inserts for Plastic.SLDPRT, 94500A221_316 Stainless Steel Button Head Hex D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]
2025-05-09 updating mech model for clearance on Cosmo U.2 guide tabs
    [92125A132_18-8 Stainless Steel Hex Drive Flat Head Screw.SLDPRT, 94459A130_Heat-Set Inserts for Plastic.SLDPRT, 94500A221_316 Stainless Steel Button Head Hex D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]
2025-05-09 updating STL for the StarTech NIC support Bracket
    [StarTech_intel_nic_support.STL]
2026-03-10 initial quote request to Sierra
    [913-0000114_BOM.xlsx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]
2026-03-10 adding stackup file and deleting individual gerbers
    [913-0000114_BOM.xlsx, stackup-K2-6lyr-FR408HR-10_MAR_2026.xlsx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]
2026-03-25 adding IPC netlist and fixed stackup file due to another typo
    [stackup-K2-6lyr-FR408HR-10_MAR_2026.xlsx, stackup-K2-6lyr-FR408HR_rev3_25_MAR_2026.xlsx, stackup_K2_6lyr_FR408HR_rev2_12_MAR_2026.xlsx]
2026-03-26 fixing another typo in the stackup spreadsheet
    [stackup-K2-6lyr-FR408HR_rev4_26_MAR_2026.xlsx]
2026-03-27 adding the PDF of the stackup Sierra wanted based on on-hand materials
2026-04-14 pcba: rev 1 release files (#5)
    [913-0000114_rev1_v1_bom.xlsx, 913-0000114_rev1_v1_stackup.xlsx]

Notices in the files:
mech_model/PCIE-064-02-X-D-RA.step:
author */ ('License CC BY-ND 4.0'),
